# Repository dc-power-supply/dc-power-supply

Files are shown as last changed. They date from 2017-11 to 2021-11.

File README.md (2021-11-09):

# DC Power Supply

<p align="center">
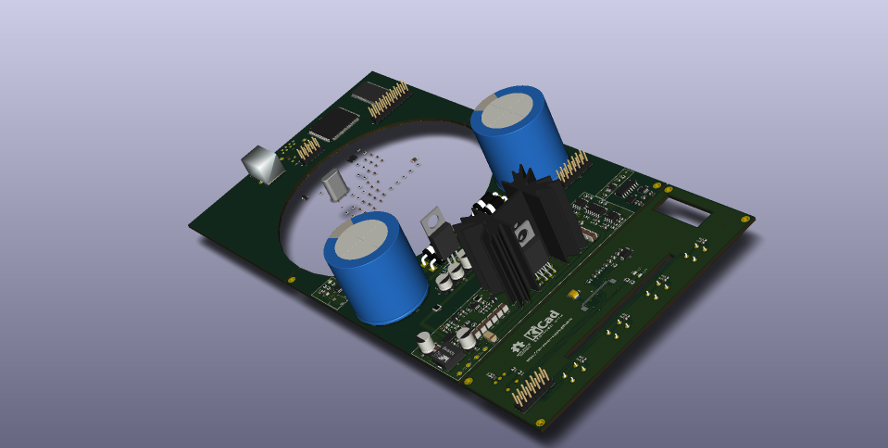
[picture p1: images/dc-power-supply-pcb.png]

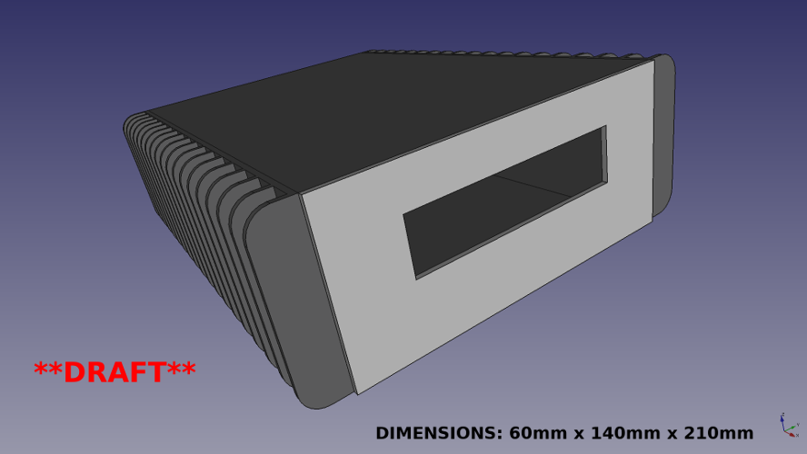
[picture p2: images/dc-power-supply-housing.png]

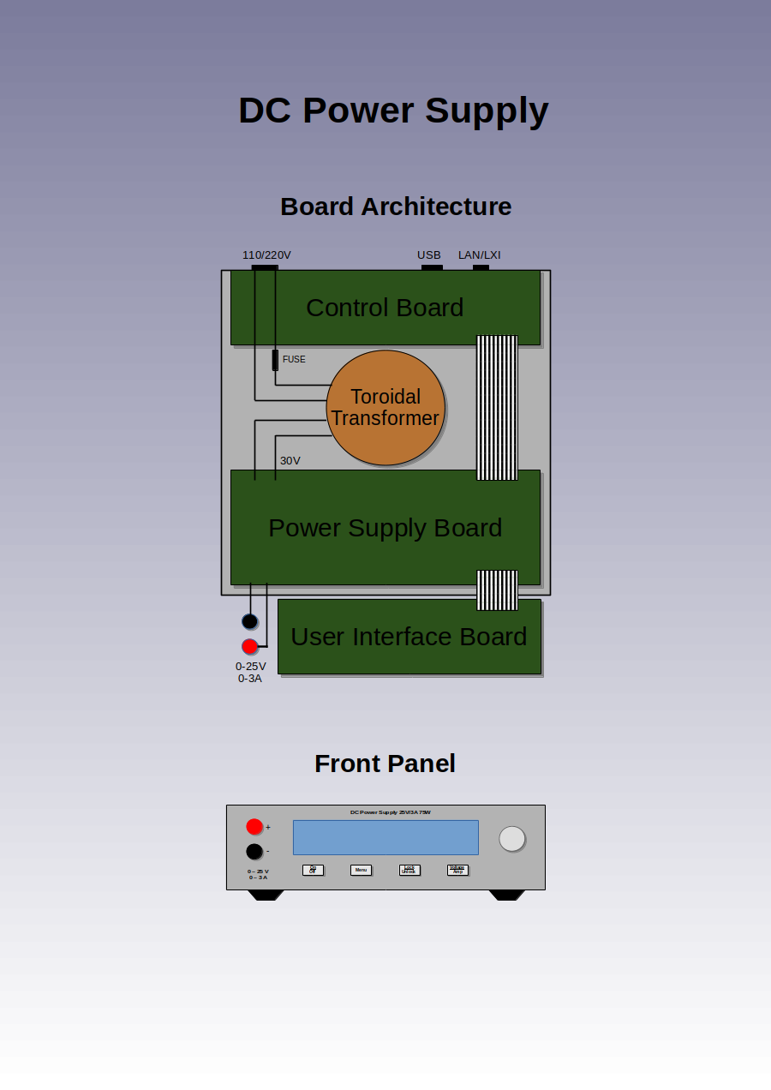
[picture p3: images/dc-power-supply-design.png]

</p>

## Description

An open source hardware (OSHW) benchtop DC power supply designed using open source tools *(WORK IN PROGRESS)*.

<br/>
<p align="center">

</p>

## Motivation

This project started as an effort to learn the ins and outs of KiCad because
the author needed to learn how to do a hardware design for a prototype (not
related to this project). However, this side project quickly grew into a thing
of its own. It reflects the ideas and features that the author wishes for a
modern benchtop DC power supply.

Also, the world needs a modern compact **fanless** OSHW DC power supply that fits
on the table of every engineer and hacker out there. Lets design one!

Hopefully it can evolve into something which one day will be good enough to be
built and maybe even produced as a kit or product. Or it can simply serve as a
learning experience on how to do OSHW design stuff on GitHub :o)

## Design goals

 - Fanless
 - Compact size
 - Stackable housing
 - Low heat dissipation (high efficiency)
 - Low noise/ripple
 - Minimum component count
 - Simple and responsive UI
 - Beautiful mechanical design
 - Get approved by DaveCad :o)

## Features

 - 0-25V / 0-3A single DC output
 - Dimensions: ~ 60mm x 140mm x 210mm (Height x Width x Depth)
 - Low peak-to-peak voltage (max 25 mVp-p)
 - Constant current (CC)
 - Constant voltage (CV)
 - Hybrid power design
   - Preregulator: Step-down switching regulator (LT8612)
   - Regulator: Linear regulator (LT3081)
 - Precision DC output/multimeter:
   - 1 mV resolution
   - 1 mA resolution
 - AC input voltmeter:
   - 100 mV resolution
 - Large OLED display (256x64) showing:
   - Output voltage
   - Output voltage limit
   - Output current
   - Output current limit
   - Output current limit hit indicator
   - Output power
   - Input voltage (AC)
   - Regulator temperature
   - IP address
 - 4 front panel buttons:
   - On/Off
   - Voltage/Current
   - Menu
   - Lock/Unlock
 - 10/100 Mbps Ethernet port
 - 110V/220V AC input switch (automatic?)
 - Toroidal transformer
 - Replaceable fuse
 - Mains on/off switch
 - Rotary encoder with push button
 - Female banana sockets with standard spacing (19mm)
 - Built in datalogger
   - 64 MB data buffer
   - Up to 1 kHz sampling of:
     - Time
     - Voltage
     - Current
 - Master/slave feature to support higher voltage or current output
   - Link control via ethernet
   - Automatic discovery of potential slaves
   - Example configurations:
     - 25V / 6A (2 units, parallel link)
     - 50V / 3A (2 units, serial link)
     - 25V / 9A (3 units, parallel link)
     - 75V / 3A (3 units, serial link)
 - Powerful MCU (NXP LPC4337)
   - 204 MHz 32-bit Cortex-M4 core
   - 204 MHz 32-bit Cortex-M0 core
 - LXI Core support (HiSlip)
   - Support for SCPI commands to:
     - Turn on/off output
     - Get/set output voltage
     - Get/set output voltage limit
     - Get output current
     - Get/set output current limit
     - Get output power
     - Get regulator temperature
     - Get/set datalogger sampling frequency
     - Start/stop datalogger
     - Dump/clear datalogger buffer
     - Dump screenshot of front display (PNG)
 - IPv4/IPv6 support

## Documentation

 - Available [here](doc)

## Design tools

 - Schematic/PCB design
   - KiCad 4.0.7 (http://kicad.org)
   - Migrate to KiCad 5.0 when it is released

<p align="center">

</p>

 - Mechanical design
   - Freecad 0.16.x (https://www.freecadweb.org)

<p align="center">

</p>

## Assembly considerations

 - Minimum SMD size is 0603 to make it feasible to still hand solder

## Todo

 - Review/refine schematics
   - Add HW ID resistors
   - Add choke
   - Add protection from toroidal inrush current
   - Add AC input voltmeter
   - Add speaker
   - Add resettable fuse (PTC)
   - Add more test points
 - Review/refine PCB layout
   - Split analog and digital ground
   - Make sure tracks are wide enough
   - Minimize parasitics
   - Add more via stitching
   - Add thermal reliefs
 - Add missing KiCad 3D models
 - Rework mechanical design
   - Must be simple and beautiful
   - As compact as possible
   - Sturdy feel
 - MCU firmware
   - Create optimized GCC toolchain (http://crosstool-ng.github.io)
   - Cortex-M4:
     - Handle power control and input/output (buttons, encoder knob, USB,
       display, ethernet/LXI)
   - Cortex-M0:
     - Handle data logging
   - Implement HiSlip protocol (server)
   - Create build system files (Make or Meson)
 - Consider using MCU LPC4367JBD208 variant
   - Adds LCD controller
   - Adds QEI (Quadrature Encoder Interface, for better rotary encoder control)
 - Implement HiSlip protocol (client) in liblxi (https://lxi.github.io)
 - Add missing documentation
 - Create BOM
 - Cost reduction
 - Build a prototype for testing

## Releases

 - Version 0.1 - First release (alpha)

## Milestones

Suggested milestones:

 - Version 1.0 - First stable release (basic features working)
 - Version 2.0 - Feature release (wifi, remote sensing)
 - Version 3.0 - Feature release (2 port LAN switch, automatic power link cable, mains inlet/outlet)

## How to contribute?

This project is fully open source - anyone who wants to contribute is welcome
to get involved.

To get started, simply clone (use 'git clone --recurse-submodules') this
repository and start making your changes.  Once done, do a pull request to push
your changes upstream. Any issues (bugs, suggestions, etc.) can be reported
and/or discussed via the GitHub issue tracker. There is also a GitHub wiki
available for editing. It's the GitHub way!

<p align="center">

</p>

**Note**: Please take care to always use the latest version of the design tools
to avoid running into compatibility issues.

**Note**: Please take care to try only push incremental changes to avoid big
bang situations.

## License

<br />This work
is licensed under a <a rel="license"
href="http://creativecommons.org/licenses/by-sa/4.0/">Creative Commons
Attribution-ShareAlike 4.0 International License</a>.

With exception of the firmware which will be released under a BSD-3 license.

##

<br/>
<br/>
<p align="center">

</p>

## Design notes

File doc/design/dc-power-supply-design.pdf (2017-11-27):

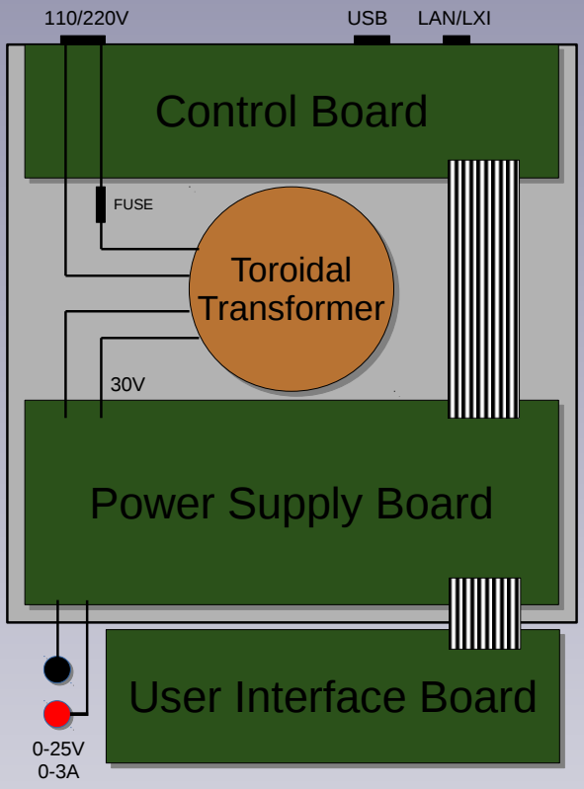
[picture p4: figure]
Control Board; Toroidal Transformer; Power Supply Board; User Interface Board; FUSE; USB; LAN/LXI

On
Off

On
Off | Menu Menu | Lock Unlock
Lock | Voltage
Amp Amp 0 – 25 V
0 – 3 A

DC Power Supply 25V/3A 75W
+

Front Panel

## DC Power Supply

Board Architecture

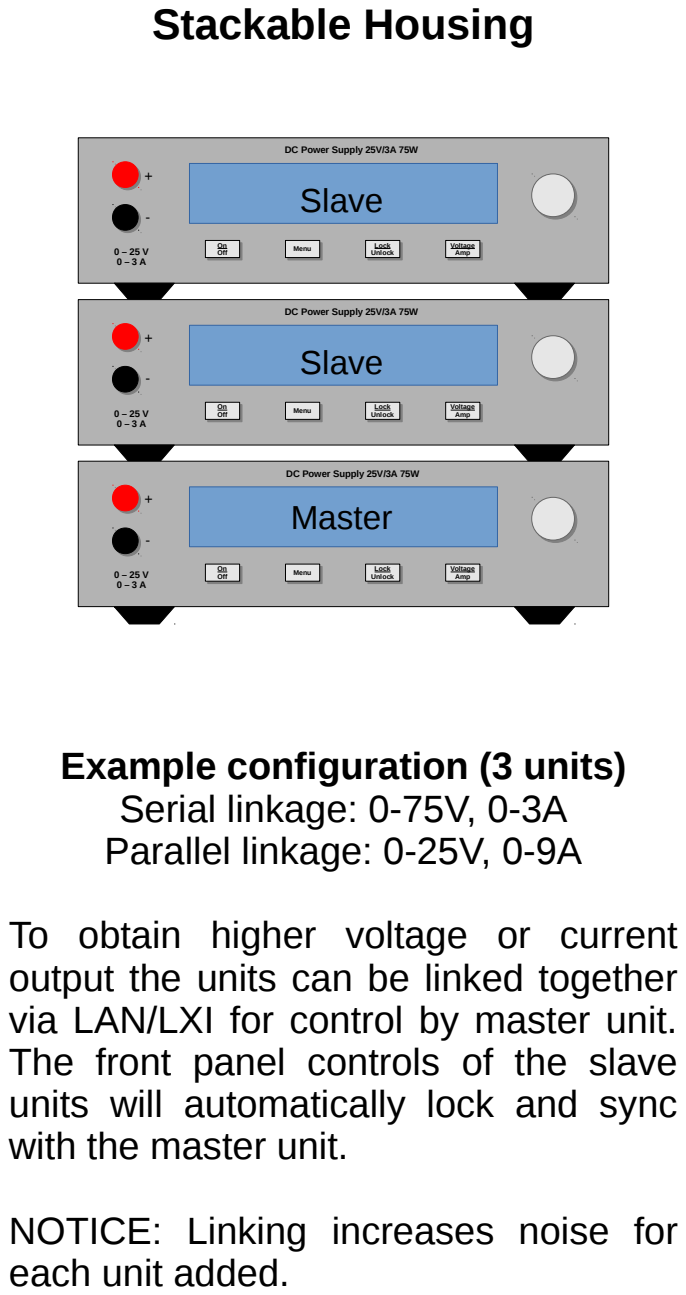
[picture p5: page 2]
Stackable Housing; On Off; Off; Menu Menu; Lock; Unlock; Voltage; Amp Amp 0 – 25 V 0 – 3 A; Voltage 0 – 25 V; Amp Amp

DC Power Supply 25V/3A 75W
Slave

Master

Example configuration (3 units)
Serial linkage: 0-75V, 0-3A
Parallel linkage: 0-25V, 0-9A

To obtain higher voltage or current
output the units can be linked together
via LAN/LXI for control by master unit.
The front panel controls of the slave
units will automatically lock and sync
with the master unit.

NOTICE: Linking increases noise for
each unit added.

Headless Variant

0 – 25 V
0 – 3 A

DC Power Supply 25V/3A 75W
+

No front controls
Remote control only (tablet, PC, etc.)

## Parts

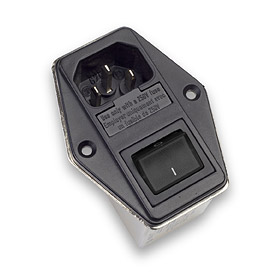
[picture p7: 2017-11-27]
doc/components/mains-inlet/produkt_375.jpg

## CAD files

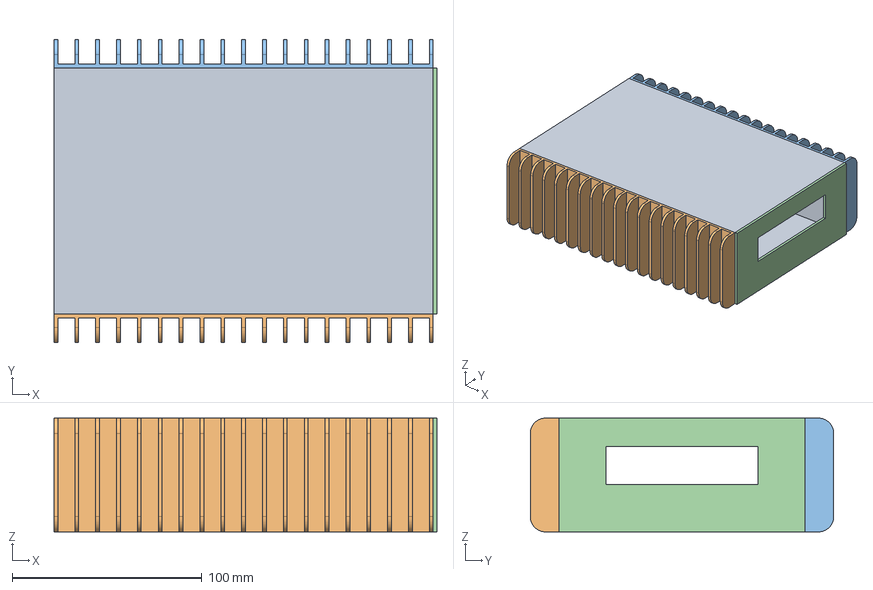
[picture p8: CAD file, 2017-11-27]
freecad/dc_power_supply.fcstd
202.0 x 160.0 x 60.0 mm
Left Heatsink
Right Heatsink

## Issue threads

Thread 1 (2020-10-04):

KiCAD v5.1.7 shows lot of airwires on board

warlock31415, 2020-10-04:
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
I just clones the repo. Noticed that there were a lot of air wires on the board. Was this design ever finished? Can i finish the board and submit a pull request?

Thanks,
Pratik

lundmar, 2020-10-04:
Hi Pratik,
Sure - feel free to upgrade it to KiCad 5.1.7 and finish up the design :+1:
I never really got around to finish up the missing microcontroller part of the PCB design. I have too many projects going on IRL :)
/Martin

warlock31415, 2020-10-04:
Okay, but i'm gonna need a little help. never worked with ethernet before. Will create more issues on here for more specific questions.

/Pratik

Closed 2020-10-04.

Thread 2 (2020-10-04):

30V output at the LT1084.

warlock31415, 2020-10-04:
Hey Martin,
I'd like to point out that you're not going to get 30V at the output of that LT1084 regulator. The MUR420 have a max 1.28V  Vf at 4A. So at full load the voltage at the input of IC2 will sag to 27.7V. This is without accounting for ripple.

At full load, the simulated ripple is ~1Vpp. Which would mean you will get 26.7V at the input to IC2. The datasheet for the regulator says the typical dropout between input and output is 1.3V.  That makes the output voltage close to 25.5V. Which would leave a 0.5V for the buck converter to play around with. I don't think this is a good safety margin.

I'd suggest going up-to a 120-50V transformer to fix this issue.

/Pratik

PS: Toroid transformers are really expensive ($145 for 50V one on digikey). Would you be willing to maybe design something a little different?

lundmar, 2020-10-04:
I think you are right on you points - 0.5V is a small margin. I recall to have concluded something similar but I don't remember the details - it's been a while since I last revisited the whole voltage chain.
I'm open to changes and suggestions and if a toroidal is a lot more expensive it would make sense to go with a classic transformer. I made the original design not so much focused on cost but rather on reducing noise.
/Martin

Closed 2020-10-11.

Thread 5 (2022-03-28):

Firmware is not found

ravi503, 2022-03-28:

lundmar, 2022-03-28:
There is no firmware - this project is stalled for now. Sorry.

Closed 2022-03-28.

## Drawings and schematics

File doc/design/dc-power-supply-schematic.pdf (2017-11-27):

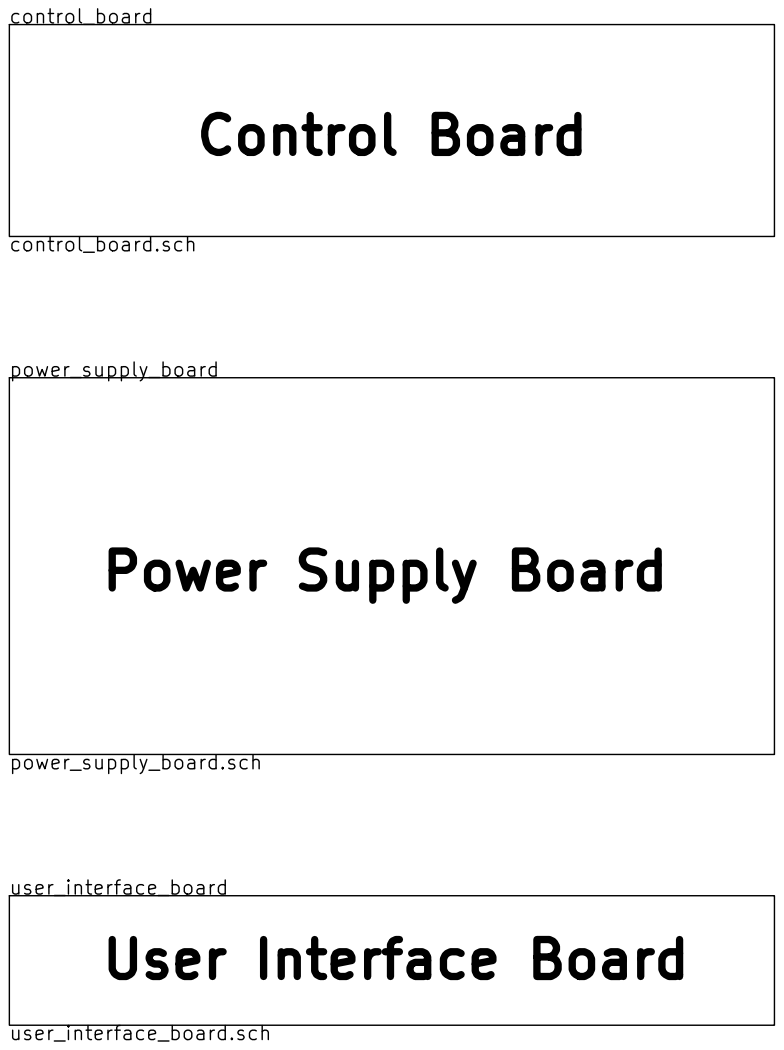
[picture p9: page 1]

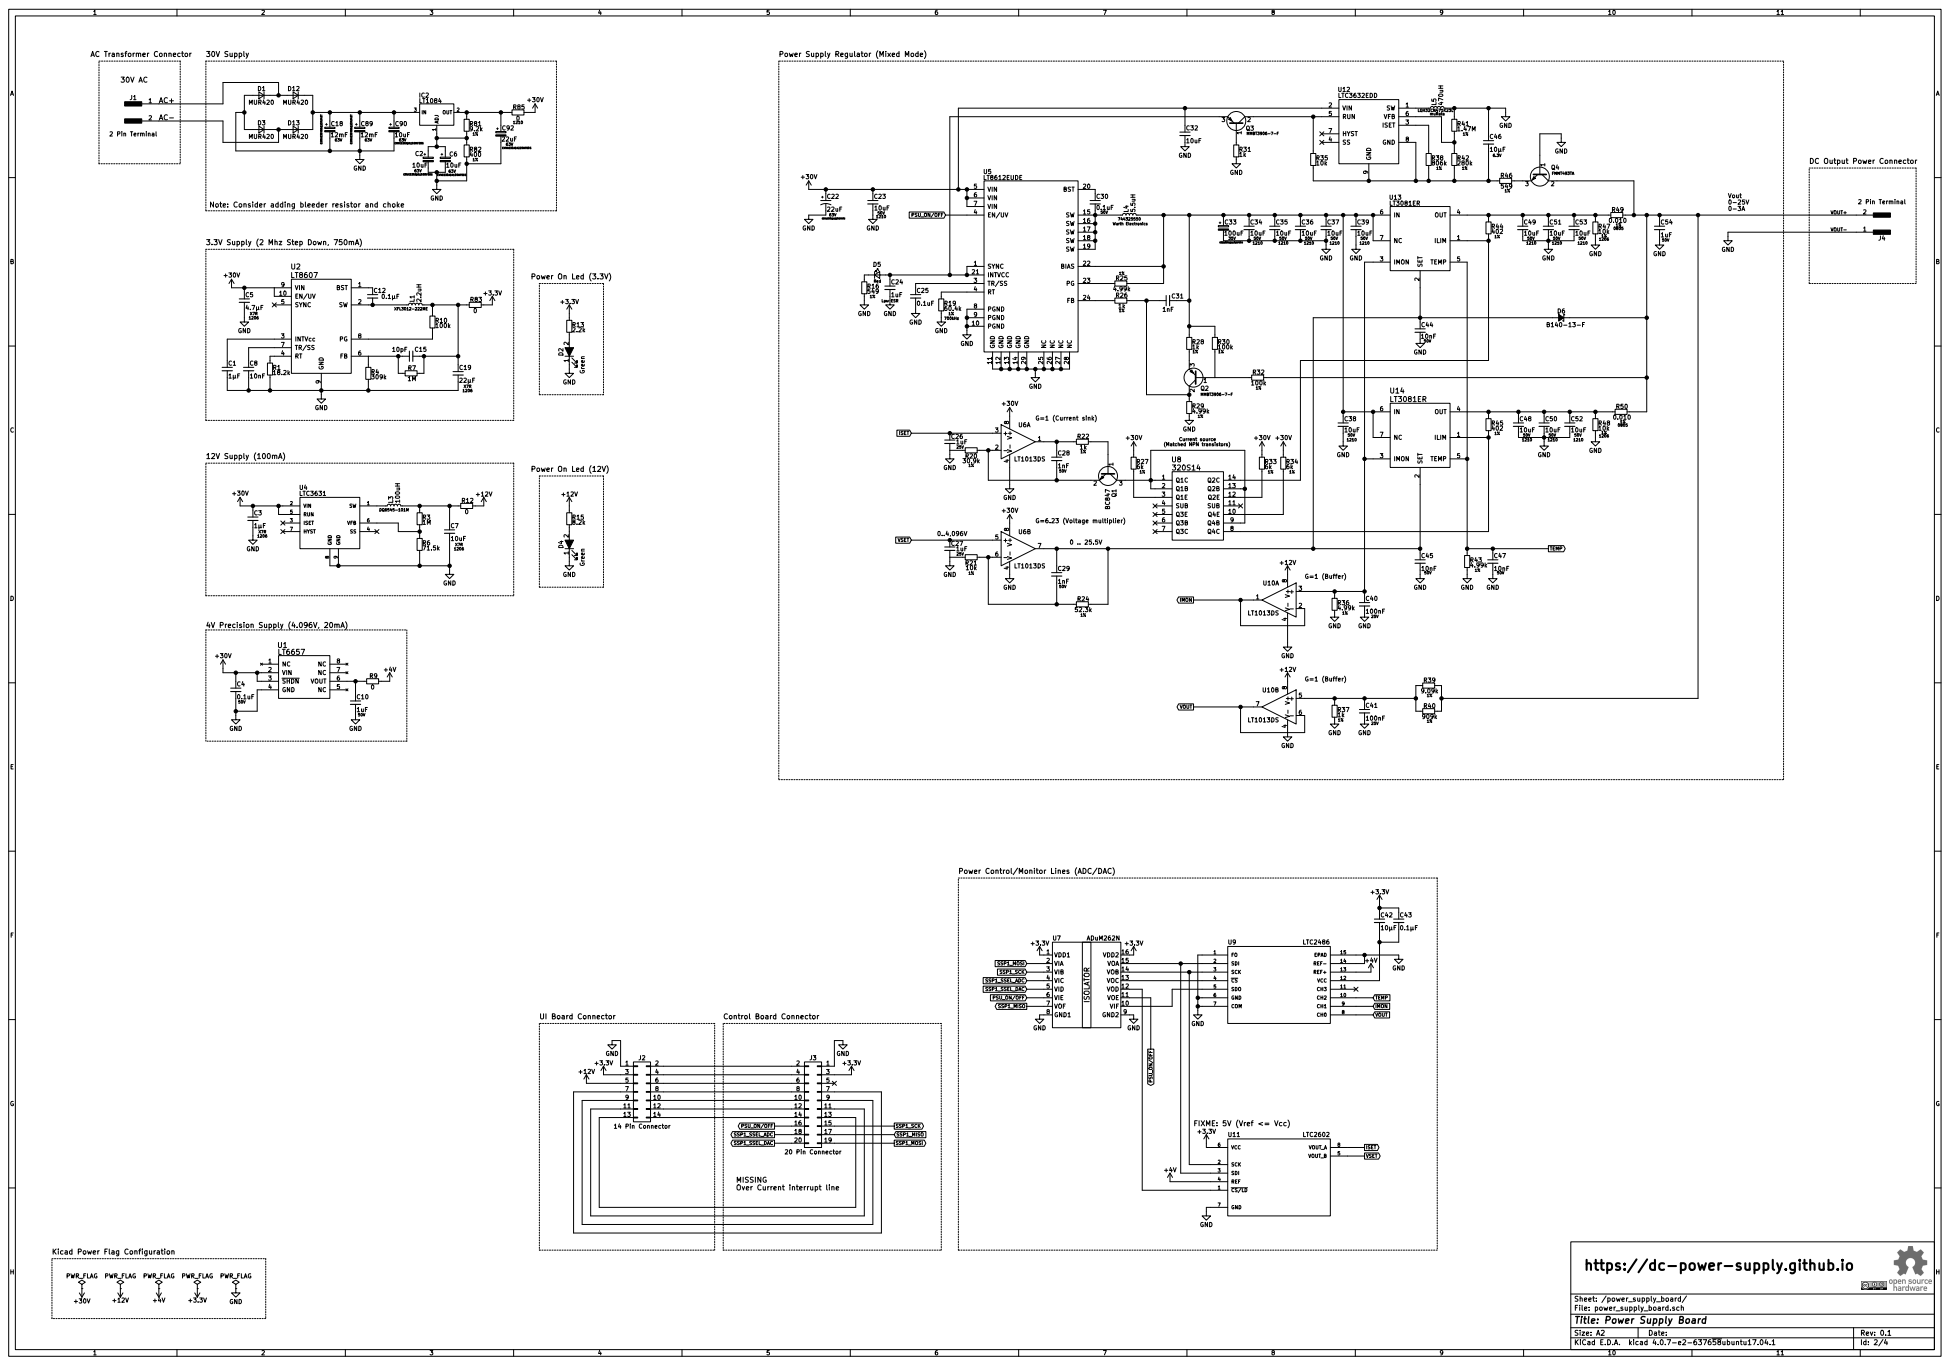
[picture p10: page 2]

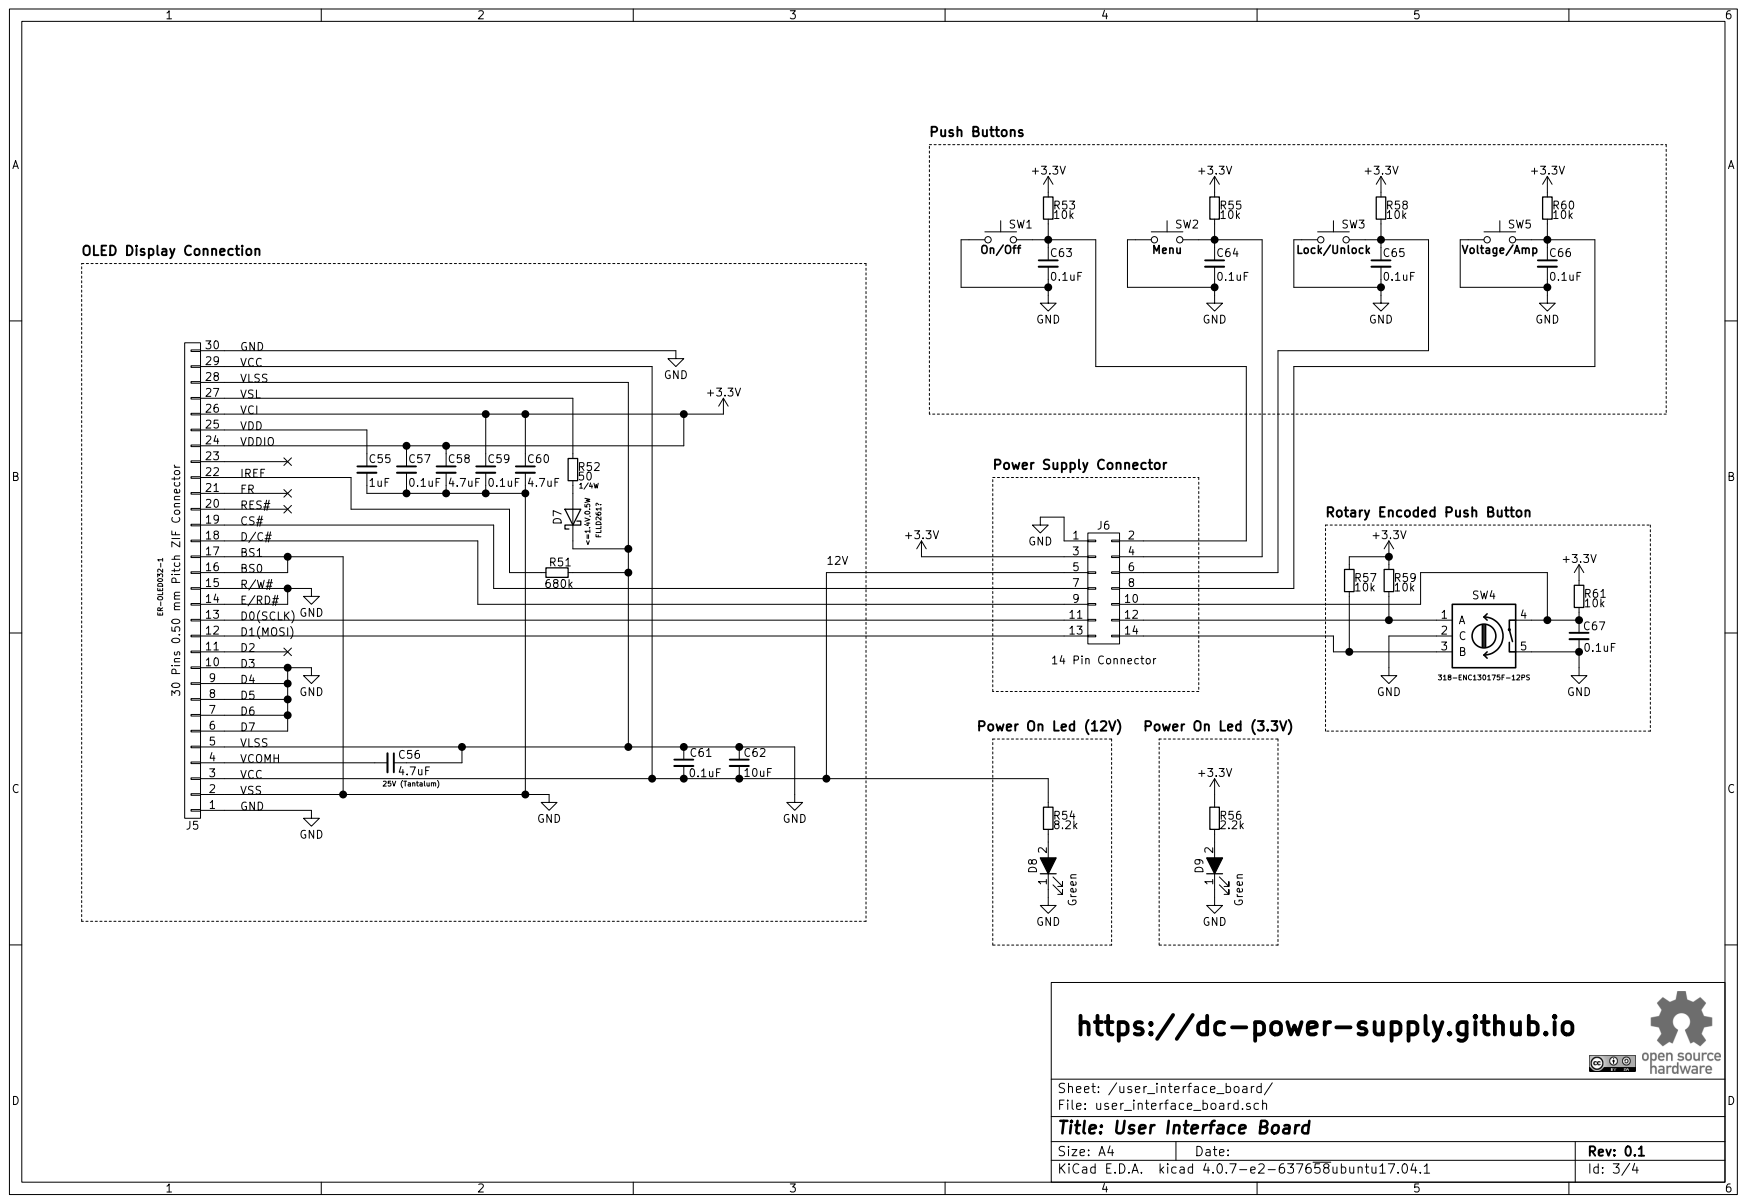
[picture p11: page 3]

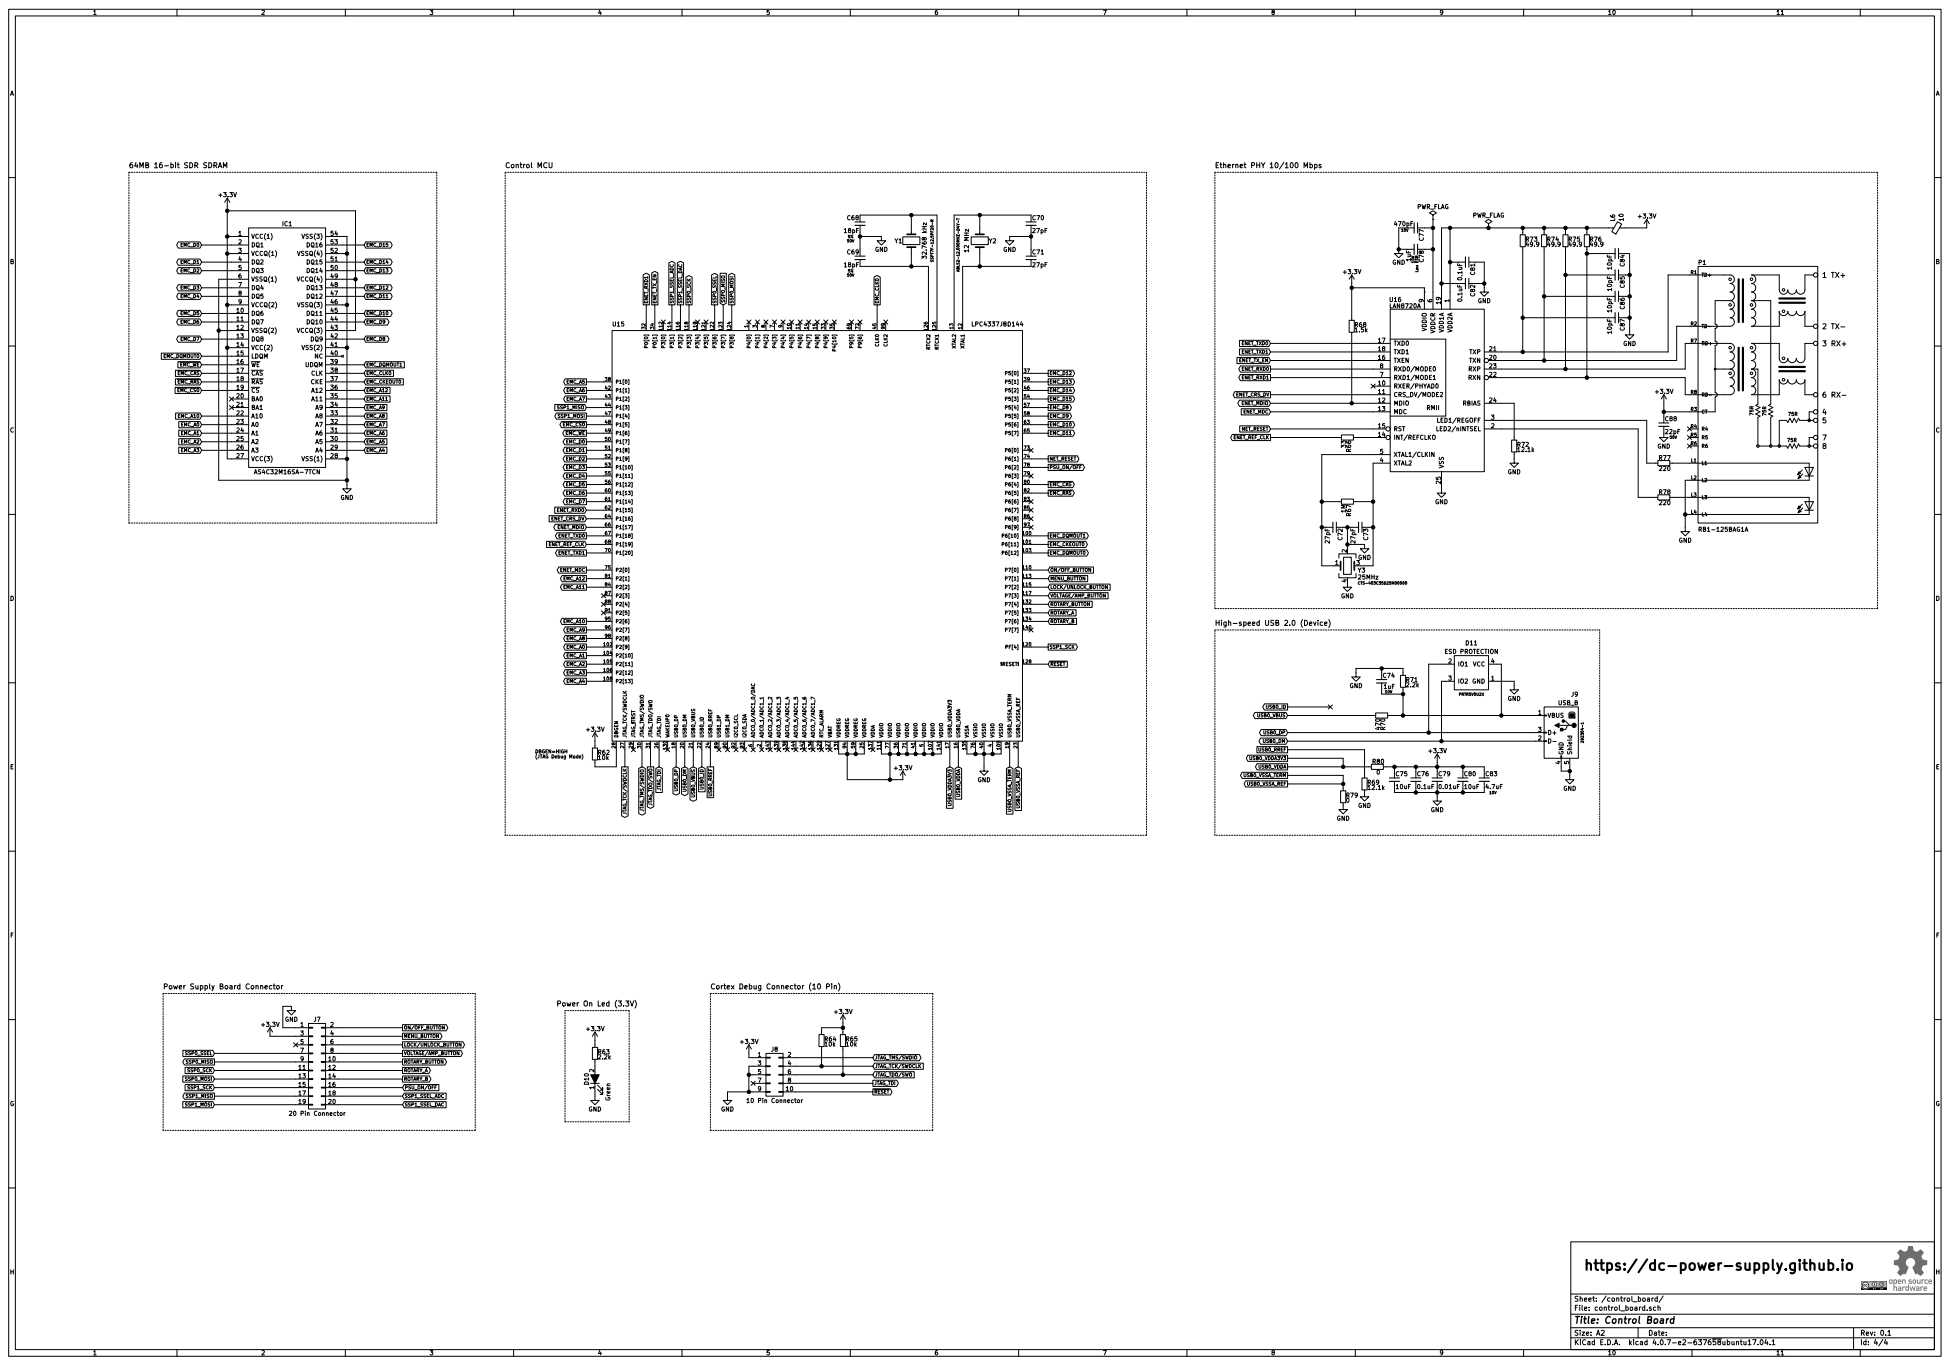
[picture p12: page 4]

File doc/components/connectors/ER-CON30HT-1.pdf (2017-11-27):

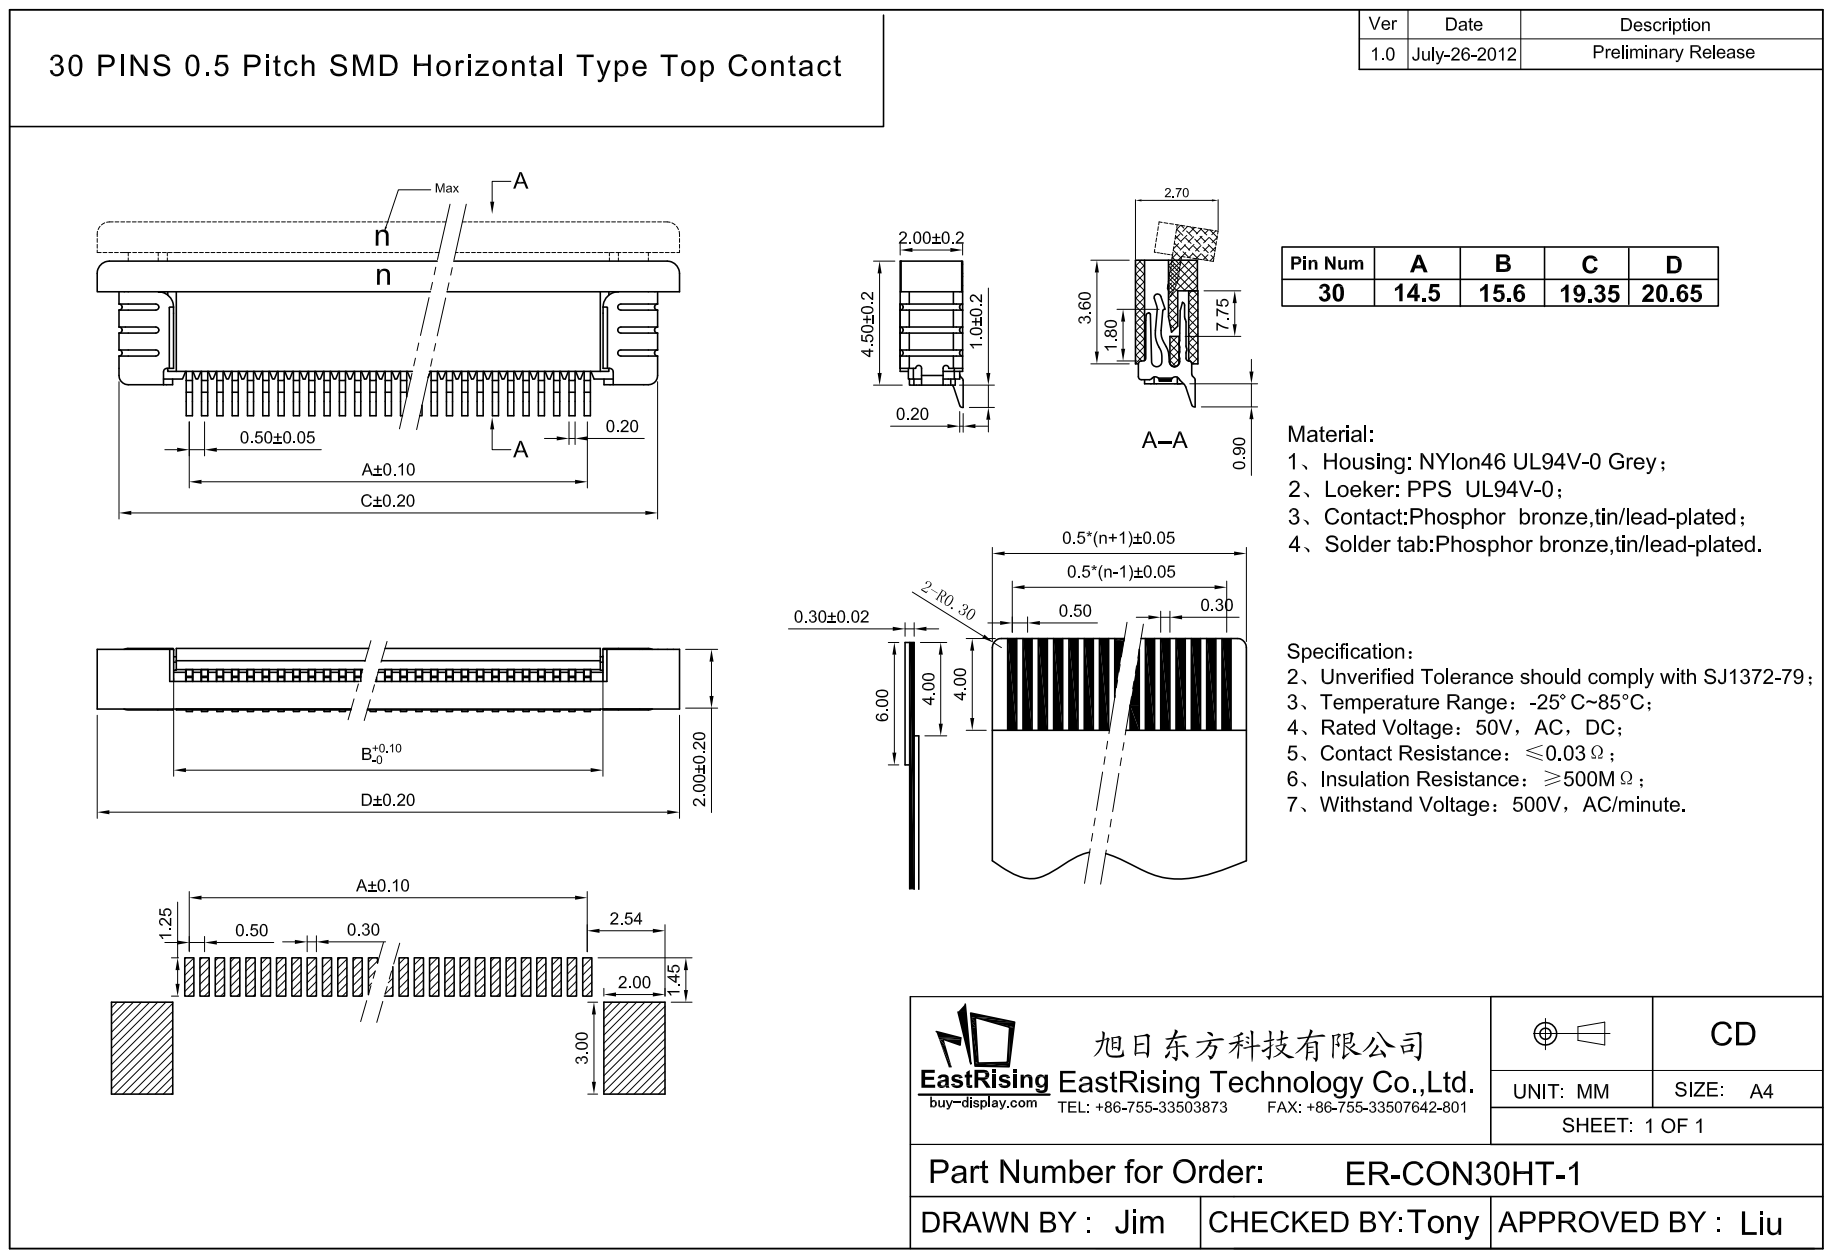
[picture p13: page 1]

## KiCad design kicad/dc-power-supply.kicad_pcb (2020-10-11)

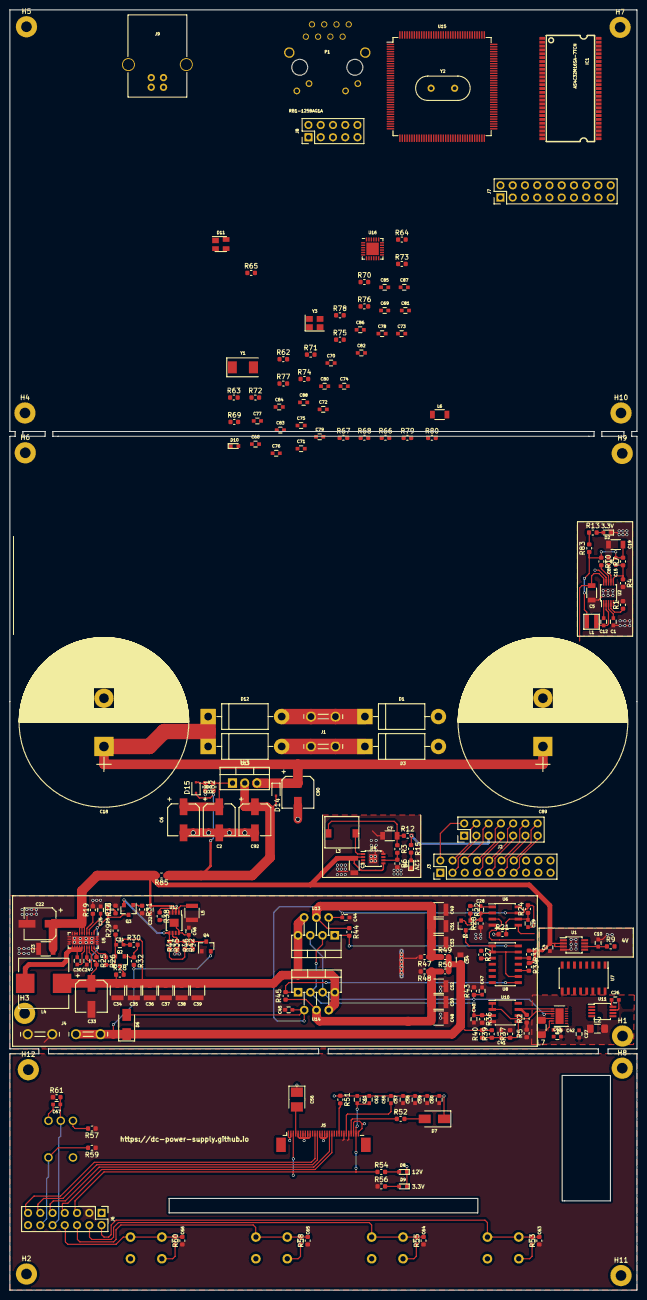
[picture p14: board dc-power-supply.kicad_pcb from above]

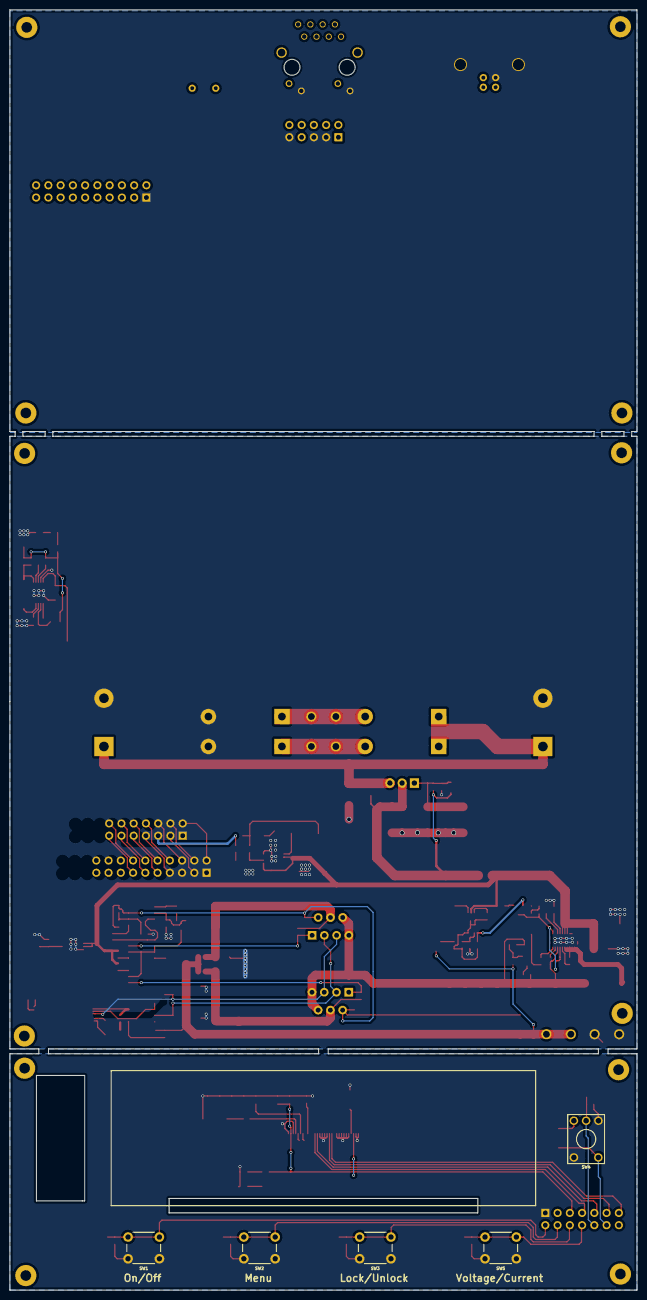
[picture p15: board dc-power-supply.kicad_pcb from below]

Board: 2 copper layers, 130.0 x 265.4 mm, 234 parts (5 on the bottom side), 197 nets.

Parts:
C1: 1μF; C_0603
C2, C6, C90: 10uF; CP_Elec_6.3x5.3
C3: 1μF; C_1206
C4, C25, C30, C57, C59, C61, C63, C64, C65, C66, C67, C76, C81, C82: 0.1uF; C_0603
C5: 4.7μF; C_1206
C7: 10uF; C_1206
C8, C44, C45, C47: 10nF; C_0603
C10, C24, C26, C27, C55, C74, C78: 1uF; C_0603
C12, C43: 0.1μF; C_0603
C15, C84, C85, C86, C87: 10pF; C_0603
C18, C89: 12mF; CP_Radial_D35.0mm_P10.00mm_SnapIn
C19: 22μF; C_1206
C22, C92: 22uF; CP_Elec_6.3x7.7
C23, C34, C35, C36, C37, C38, C39, C48, C49, C50, C51, C52, C53: 10uF; C_1210
C28, C29, C31: 1nF; C_0603
C32, C62, C75, C80: 10uF; C_0603
C33: 100uF; CP_Elec_6.3x7.7
C40, C41: 100nF; C_0603
C42, C46: 10μF; C_0603
C54: 1uF; C_0805
C56: 4.7uF; CP_Tantalum_Case-B_EIA-3528-21_Reflow
C58, C60, C83: 4.7uF; C_0603
C68, C69: 18pF; C_0603
C70, C71, C72, C73: 27pF; C_0603
C77: 470pF; C_0603
C79: 0.01uF; C_0603
C88: 22pF; C_0603
D1, D3, D12, D13: MUR420; D_DO-201AD_P15.24mm_Horizontal
D2, D4, D8, D9, D10: Green; LED_0603
D5: Red; LED_0603
D6: B140-13-F; D_SMA
D7: <=1.4V,0.5W; D_SMA
D11: ESD PROTECTION; SOT-143
D14, D15: BAT54; D_SOD-323F
H1, H2, H3, H4, H5, H6, H7, H8, H9, H10, H11, H12: MountingHole; MountingHole_2.2mm_M2_Pad
IC1: AS4C32M16SA-7TCN; TSOP-54
J1, J4: 2 Pin Terminal; 2_tab_250
J2, J6: 14 Pin Connector; Pin_Header_Straight_2x07_Pitch2.54mm
J3, J7: 20 Pin Connector; Pin_Header_Straight_2x10_Pitch2.54mm
J5: 30 Pins 0.50 mm Pitch ZIF Connector; Molex_Plug_1x30_Pitch0.5mm
J8: 10 Pin Connector; Pin_Header_Straight_2x05_Pitch2.54mm
J9: USB_B
L1: 2.2uH; XFL3012
L2, L7: Ferrite_Bead_Small; R_1206_3216Metric_Pad1.42x1.75mm_HandSolder
L3: 100uH; DQ6545
L4: 5.5uH; Inductor_Wurth_HCI-1050
L5: 470uH; R_1210
L6: 10; C_1206
P1: RB1-125BAG1A; WIZNET_RB1-125BAG1A
Q1: BC847; SOT-23
Q2, Q3: MMBT3906-7-F; SOT-23
Q4: FMMT493TA; SOT-23
R1: 18.2k; R_0603_1608Metric
R2, R10, R30, R32: 100k; R_0603_1608Metric
R3, R7, R67: 1M; R_0603_1608Metric
R4: 309k; R_0603_1608Metric
R5, R22, R26, R28, R31, R37: 1k; R_0603_1608Metric
R6: 71.5k; R_0603_1608Metric
R9, R12, R79, R80, R83, R85: 0; R_0603_1608Metric
R13, R56, R63, R71: 2.2k; R_0603_1608Metric
R15, R54: 8.2k; R_0603_1608Metric
R16, R46: 549; R_0603_1608Metric
R19: 60.4k; R_0603_1608Metric
R20: 30.9k; R_0603_1608Metric
R21, R35, R47, R48, R53, R55, R57, R58, R59, R60, R61, R62, R64, R65: 10k; R_0603_1608Metric
R24: 52.3k; R_0603_1608Metric
R25, R29, R36, R43: 4.99k; R_0603_1608Metric
R27, R33, R34: 6k; R_0603_1608Metric
R38: 806k; R_0603_1608Metric
R39: 9.09k; R_0603_1608Metric
R40: 909k; R_0603_1608Metric
R41: 1.47M; R_0603_1608Metric
R42: 280k; R_0603_1608Metric
R44, R45: 402; R_0603_1608Metric
R49, R50: 0.010; R_0603_1608Metric
R51: 680k; R_0603_1608Metric
R52: 50; R_0603_1608Metric
R66: 33; R_0603_1608Metric
R68: 1.5k; R_0603_1608Metric
R69, R72: 12.1k; R_0603_1608Metric
R70: 470; R_0603_1608Metric
R73, R74, R75, R76: 49.9; R_0603_1608Metric
R77, R78: 220; R_0603_1608Metric
R81: 4.75k; R_0603_1608Metric
R82: 200; R_0603_1608Metric
SW1: On/Off; SW_PUSH_6mm
SW2: Menu; SW_PUSH_6mm
SW3: Lock/Unlock; SW_PUSH_6mm
SW4: 318-ENC130175F-12PS; KSA_Tactile_SPST
SW5: Voltage/Amp; SW_PUSH_6mm
U1: LT6657; MSOP-8_3x3mm_Pitch0.65mm
U2: LT8607; MSOP-10_3x3mm_Pitch0.5mm
U3: LM338T; TO-220-3_Vertical
U4: LTC3631; MSOP-8-1EP_3x3mm_Pitch0.65mm
U5: LT8612EUDE; QFN-28-1EP_3x6mm_Pitch0.5mm
U6, U10: LT1013DS; SOIC-8_3.9x4.9mm_Pitch1.27mm
U7: ADuM262N; SOIC-16_3.9x9.9mm_Pitch1.27mm
U8: 320S14; SOIC-14_3.9x8.7mm_Pitch1.27mm
U9: LTC2486; DFN-14-1EP_3x4mm_Pitch0.5mm
U11: LTC2602; MSOP-8_3x3mm_Pitch0.65mm
U12: LTC3632EDD; MSOP-8-1EP_3x3mm_Pitch0.65mm
U13, U14: LT3081ER; TO-220-7_Vertical_StaggeredType2
U15: LPC4337JBD144; LQFP-144_20x20mm_Pitch0.5mm
U16: LAN8720A; QFN-24-1EP_4x4mm_Pitch0.5mm
Y1: 32.768 kHz; Crystal_SMD_0603-2pin_6.0x3.5mm
Y2: 12 MHz; Crystal_HC49-U_Vertical
Y3: 25MHz; Crystal_SMD_3225-4pin_3.2x2.5mm

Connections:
+3V3: C42.1, C43.1, C57.1, C58.1, C59.1, C60.1, C75.1, C76.1, C79.1, C80.1, C83.1, C88.1, IC1.1, IC1.3, IC1.9, IC1.14, IC1.27, IC1.43, IC1.49, J2.3, J3.3, J5.24, J5.26, J6.3, J7.3, J8.1, L2.2, L6.2, L7.1, P1.R3, R13.1, R53.1, R55.1, R56.1, R57.1, R58.1, R59.1, R60.1, R61.1, R62.1, R63.1, R64.1, R65.1, R68.1, R80.2, R83.2, U7.1, U7.16, U9.12, U11.6, U15.5, U15.25, U15.36, U15.41, U15.59, U15.71, U15.77, U15.94, U15.107, U15.111, U15.131, U15.141, U16.9
+12V: J2.5, R12.2, R15.1, U10.8
+30V: C3.1, C4.1, C5.1, C22.1, C23.1, C32.1, R27.1, R33.1, R34.1, R85.2, U1.2, U1.3, U2.10, U4.2, U4.5, U5.5, U5.6, U5.7, U6.8, U12.2
/power_supply_board/AC+: D1.1, D12.2, J1.1
/power_supply_board/AC-: D3.1, D13.2, J1.2
/power_supply_board/VOUT+: C54.1, D6.1, J4.2, Q4.2, R32.2, R39.2, R40.2, R49.2, R50.2
EMC_A0: IC1.23, U15.102
EMC_A1: IC1.24, U15.104
EMC_A2: IC1.25, U15.105
EMC_A3: IC1.26, U15.106
EMC_A4: IC1.29, U15.108
EMC_A5: IC1.30, U15.38
EMC_A6: IC1.31, U15.42
EMC_A7: IC1.32, U15.43
EMC_A8: IC1.33, U15.98
EMC_A9: IC1.34, U15.96
EMC_A10: IC1.22, U15.95
EMC_A11: IC1.35, U15.84
EMC_A12: IC1.36, U15.81
EMC_CKEOUT0: IC1.37, U15.101
EMC_CLK0: IC1.38, U15.45
EMC_D0: IC1.2, U15.50
EMC_D1: IC1.4, U15.51
EMC_D2: IC1.5, U15.52
EMC_D3: IC1.7, U15.53
EMC_D4: IC1.8, U15.55
EMC_D5: IC1.10, U15.56
EMC_D6: IC1.11, U15.60
EMC_D7: IC1.13, U15.61
EMC_D8: IC1.42, U15.57
EMC_D9: IC1.44, U15.58
EMC_D10: IC1.45, U15.63
EMC_D11: IC1.47, U15.65
EMC_D12: IC1.48, U15.37
EMC_D13: IC1.50, U15.39
EMC_D14: IC1.51, U15.46
EMC_D15: IC1.53, U15.54
EMC_DQMOUT0: IC1.15, U15.103
EMC_DQMOUT1: IC1.39, U15.100
ENET_CRS_DV: U15.64, U16.11
ENET_MDC: U15.75, U16.13
ENET_MDIO: R68.2, U15.66, U16.12
ENET_REF_CLK: R66.2, U15.68
ENET_RXD0: U15.62, U16.8
ENET_RXD1: U15.32, U16.7
ENET_TXD0: U15.67, U16.17
ENET_TXD1: U15.70, U16.18
ENET_TX_EN: U15.34, U16.16
GND: C1.2, C2.2, C3.2, C4.2, C5.2, C6.2, C7.2, C8.2, C10.2, C18.2, C19.2, C22.2, C23.2, C24.2, C25.2, C26.2, C27.2, C32.2, C33.2, C34.2, C35.2, C36.2, C37.2, C38.2, C39.2, C40.2, C41.2, C42.2, C43.2, C44.2, C45.2, C46.1, C47.2, C48.2, C49.2, C50.2, C51.2, C52.2, C53.2, C54.2, C55.2, C56.1, C57.2, C58.2, C59.2, C60.2, C61.1, C62.1, C63.2, C64.2, C65.2, C66.2, C67.2, C68.2, C69.1, C70.2, C71.1, C72.1, C73.2, C74.1, C75.2, C76.2, C77.2, C78.2, C79.2, C80.2, C81.1, C82.1, C83.2, C84.1, C85.1, C86.1, C87.1, C88.2, C89.2, C90.2, C92.2, D1.2, D2.1, D3.2, D4.1, D7.1, D8.1, D9.1, D10.1, D11.1, IC1.6, IC1.12, IC1.28, IC1.41, IC1.46, IC1.52, IC1.54, J2.1, J3.1, J4.1, J5.1, J5.2, J5.5, J5.6, J5.7, J5.8, J5.9, J5.10, J5.14, J5.15, J5.16, J5.17, J5.28, J5.30, J6.1, J7.1, J8.3, J8.5, J8.9, J9.4, J9.5, L5.2, P1.L2, P1.L4, Q4.1, R1.2, R4.2, R5.1, R6.2, R16.2, R19.2, R20.1, R21.1, R29.2, R31.2, R36.2, R37.2, R41.1, R43.2, R47.2, R48.2, R51.1, R69.2, R71.1, R72.2, R79.2, R82.2, SW1.1, SW2.1, SW3.1, SW4.2, SW4.5, SW5.1, U1.4, U2.9, U4.8, U4.9, U5.8, U5.9, U5.10, U5.11, U5.12, U5.13, U5.14, U5.25, U5.26, U5.27, U5.28, U5.29, U6.4, U7.8, U7.9, U9.1, U9.6, U9.7, U9.14, U9.15, U10.4, U11.7, U15.4, U15.40, U15.76, U15.109, U15.135, U16.25, Y3.2, Y3.4
IMON: U9.9, U10.1, U10.2
ISET: C26.1, U6.3, U11.8
JTAG_TCK/SWDCLK: J8.4, R64.2, U15.27
JTAG_TDI: J8.8, U15.26
JTAG_TDO/SWO: J8.6, R65.2, U15.31
JTAG_TMS/SWDIO: J8.2, U15.30
LOCK/UNLOCK_BUTTON: J7.6, U15.115
MENU_BUTTON: J7.4, U15.113
NET_RESET: U15.74, U16.15
unnamed: C1.1, U2.3
unnamed: C2.1, C6.1, D15.2, R81.2, R82.1, U3.1
unnamed: C7.1, L3.2, R3.1, R12.1
unnamed: C8.1, U2.7
unnamed: C10.1, R9.1, U1.6
unnamed: C12.1, U2.1
unnamed: C12.2, L1.1, U2.2
unnamed: C15.1, R4.1, R7.1, U2.6
unnamed: C15.2, C19.1, L1.2, R7.2, R10.1, R83.1
unnamed: C18.1, C89.1, C90.1, D12.1, D13.1, D14.1, U3.3
unnamed: C24.1, D5.2, Q3.3, U5.1, U5.21
unnamed: C25.1, U5.3
unnamed: C28.1, R22.1, U6.1
unnamed: C28.2, Q1.2, R20.2, U6.2
unnamed: C29.1, C44.1, C45.1, D6.2, R24.2, U6.7, U13.2, U14.2
unnamed: C29.2, R21.2, R24.1, U6.6
unnamed: C30.1, U5.20
unnamed: C30.2, L4.1, U5.15, U5.16, U5.17, U5.18, U5.19
unnamed: C31.1, Q2.2, R26.2, R29.1
unnamed: C31.2, C33.1, C34.1, C35.1, C36.1, C37.1, C38.1, C39.1, L4.2, R25.2, R28.1, R30.1, U5.22, U13.6, U13.7, U14.6, U14.7
unnamed: C40.1, R36.1, U10.3, U13.3, U14.3
unnamed: C41.1, R37.1, R39.1, R40.1, U10.5
unnamed: C46.2, R35.2, R38.2, R42.2, R46.1, U12.8, U12.9
unnamed: C48.1, C50.1, C52.1, R45.1, R48.1, R50.1, U14.4
unnamed: C49.1, C51.1, C53.1, R44.1, R47.1, R49.1, U13.4
unnamed: C55.1, J5.25
unnamed: C56.2, J5.4
unnamed: C61.2, C62.2, J5.3, J5.29, J6.5, R54.1
unnamed: C63.1, J6.2, R53.2, SW1.2
unnamed: C64.1, J6.4, R55.2, SW2.2
unnamed: C65.1, J6.6, R58.2, SW3.2
unnamed: C66.1, J6.8, R60.2, SW5.2
unnamed: C67.1, J6.10, R61.2, SW4.4
unnamed: C68.1, U15.125, Y1.1
unnamed: C69.2, U15.126, Y1.2
unnamed: C70.1, U15.13, Y2.1
unnamed: C71.2, U15.12, Y2.2
unnamed: C72.2, R67.2, U16.5, Y3.1
unnamed: C73.1, R67.1, U16.4, Y3.3
unnamed: C74.2, D11.4, J9.1, R70.1, R71.2
unnamed: C77.1, C78.1, U16.6
unnamed: C81.2, C82.2, L6.1, R73.1, R74.1, R75.1, R76.1, U16.1, U16.19
unnamed: C84.2, P1.R8, R76.2, U16.22
unnamed: C85.2, P1.R7, R75.2, U16.23
unnamed: C86.2, P1.R2, R74.2, U16.20
unnamed: C87.2, P1.R1, R73.2, U16.21
unnamed: C92.1, D14.2, D15.1, R81.1, R85.1, U3.2
unnamed: D2.2, R13.2
unnamed: D4.2, R15.2
unnamed: D5.1, R16.1
unnamed: D7.2, R52.2
unnamed: D8.2, R54.2
unnamed: D9.2, R56.2
unnamed: D10.2, R63.2
unnamed: J2.2, J3.2
unnamed: J2.4, J3.4
unnamed: J2.6, J3.6
unnamed: J2.7, J3.7
unnamed: J2.8, J3.8
unnamed: J2.9, J3.9
unnamed: J2.10, J3.10
unnamed: J2.11, J3.11
unnamed: J2.12, J3.12
unnamed: J2.13, J3.13
unnamed: J2.14, J3.14
unnamed: J5.12, J6.13
unnamed: J5.13, J6.11
unnamed: J5.18, J6.9
unnamed: J5.19, J6.7
unnamed: J5.22, R51.2
unnamed: J5.27, R52.1
unnamed: J6.12, R59.2, SW4.1
unnamed: J6.14, R57.2, SW4.3
unnamed: L2.1, U11.4
unnamed: L3.1, U4.1
unnamed: L5.1, U12.1
unnamed: L7.2, U9.13
unnamed: P1.L1, R77.2
unnamed: P1.L3, R78.2
unnamed: Q1.1, R22.2
unnamed: Q1.3, U8.1, U8.2, U8.9, U8.13
unnamed: Q2.1, R30.2, R32.1
unnamed: Q2.3, R28.2
unnamed: Q3.1, R31.1
unnamed: Q3.2, R35.1, U12.5
unnamed: Q4.3, R46.2
unnamed: R1.1, U2.4
unnamed: R2.1, R5.2, U10.6
unnamed: R3.2, R6.1, U4.6
unnamed: R10.2, U2.8
unnamed: R19.1, U5.4
unnamed: R25.1, U5.23
unnamed: R26.1, U5.24
unnamed: R27.2, U8.3
unnamed: R33.2, U8.12
unnamed: R34.2, U8.10
unnamed: R38.1, U12.3
unnamed: R41.2, R42.1, U12.6
unnamed: R44.2, U8.14, U13.1
unnamed: R45.2, U8.8, U14.1
unnamed: R62.2, U15.28
unnamed: R66.1, U16.14
unnamed: R72.1, U16.24
unnamed: R77.1, U16.3
unnamed: R78.1, U16.2
unnamed: U7.10, U9.5
unnamed: U7.13, U9.4
unnamed: U7.12, U11.1
unnamed: U7.14, U9.3, U11.2
unnamed: U7.15, U9.2, U11.3
ON/OFF_BUTTON: J7.2, U15.110
PSU_ON/OFF: J3.16, J7.16, U7.6, U7.11, U15.78
ROTARY_A: J7.12, U15.133
ROTARY_B: J7.14, U15.134
ROTARY_BUTTON: J7.10, U15.132
SSP0_MISO: J7.9, U15.123
SSP0_MOSI: J7.13, U15.124
SSP0_SCK: J7.11, U15.118
SSP0_SSEL: J7.7, U15.122
SSP1_MISO: J3.17, J7.17, U7.7, U15.44
SSP1_MOSI: J3.19, J7.19, U7.2, U15.47
SSP1_SCK: J3.15, J7.15, U7.3, U15.120
SSP1_SSEL_ADC: J3.18, J7.18, U7.4, U15.114
SSP1_SSEL_DAC: J3.20, J7.20, U7.5, U15.116
TEMP: C47.1, R43.1, U9.10, U13.5, U14.5
USB0_DM: D11.3, J9.2, U15.20
USB0_DP: D11.2, J9.3, U15.18
USB0_RREF: R69.1, U15.24
USB0_VBUS: R70.2, U15.21
USB0_VDDA: R80.1, U15.16, U15.17
USB0_VSSA_REF: R79.1, U15.19, U15.23
VOLTAGE/AMP_BUTTON: J7.8, U15.117
VOUT: R2.2, U9.8, U10.7
VSET: C27.1, U6.5, U11.5
~EMC_CAS: IC1.17, U15.80
~EMC_CS0: IC1.19, U15.48
~EMC_RAS: IC1.18, U15.82
~EMC_WE: IC1.16, U15.49
~RESET: J8.10, U15.128

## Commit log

2017-11-27 Import files
    [control_board.sch, dc-power-supply.kicad_pcb, dc-power-supply.sch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]
2020-10-04 Made some major and minor design changes
    * Decided on using a 40VAC transformer instead of a toroid. This freed up a lot space for the uC board.
    * Switched to a LM338T regulator from TI instead of the more expensive LT part
    - Added protection diode
    - Changed values of feedback resistors to account for minimum load current
    * Added a Ferrite bead to +3v3 Rail and used it for reference for the ADC and the DAC. This fixes the Vref > Vcc issue. Don't need the precision 4V supply anymore
    * Changed U10B to a Non-inverting Amp with a G = 1000. This gives us a higher voltage to work with. Was originally 0.6mV at max output current.
    * Fixed connection issues on U9 where the decoupling caps wer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
    [control_board-2020-10-04-00-54-10.sch, control_board-2020-10-04-00-54-30.sch, control_board-2020-10-04-09-08-37.sch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]
2021-11-09 Update README.md
    https://forum.kicad.info/t/warning-avoid-all-links-to-kicad-pcb-org-use-kicad-org/31521
